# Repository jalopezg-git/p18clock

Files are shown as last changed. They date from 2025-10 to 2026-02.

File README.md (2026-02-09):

# p18clock: a PIC18-based alarm clock

## Introduction
p18clock is an alarm clock based on a PIC18F2550 microcontroller.
The project leverages the [libledmtx](https://github.com/jalopezg-git/libledmtx/) library to drive a LED dot matrix display.

p18clock includes the following features:
- Time and date function
- Display temperature in degrees Celsius
- 24h alarm
- AUTO: display current time, but start a vertical scroll showing additional lines (day-of-the-week, day-of-the-month and month, temperature) every five minutes.

[p18clock-unsharp.mp4](https://github.com/user-attachments/assets/c53c3382-a4fd-4352-af9d-7081afe7f925)

The clock is based on a finite state machine that is described in the following diagram.
It has four push buttons: MODE, SET, UP, DOWN.  MODE triggers the transition between main states.  SET can be used to cycle across sub-states.  UP/DOWN can be used to change the value for a setting.
For more information, see the [p18clock user manual](https://github.com/jalopezg-git/p18clock/blob/master/user-manual/INDEX-EN.md).

```
                                             B_MODE
        ,-----------------------------------------------------------------------------------.
       v                                                                                    `|
 +------------+        +------------+        +------------+        +-------------+        +------------+
 | STATE_TIME | -----> | STATE_DATE | -----> | STATE_TEMP | -----> | STATE_ALARM | -----> | STATE_AUTO |
 +------------+ B_MODE +------------+ B_MODE +------------+ B_MODE +-------------+ B_MODE +------------+
    |       ^             |       ^             |      ^              |        ^
    | B_SET  \            | B_SET  \            | B_SET \             | B_SET  |
    v         `           v         `           v        `            v         `
 +----------+  `       +----------+  `       +---------+  `        +----------+  `
 | _SETHOUR |  |       | _SETMDAY |  |       | _SETVDD |  |        | _SETHOUR |  |
 +----------+  |       +----------+  |       +---------+  |        +----------+  |
    | B_SET    |          | B_SET    |          | B_SET   |           | B_SET    |
    v          |          v          |          v         |           v          |
 +----------+  ,       +----------+  |       +---------+  ,        +----------+  ,
 | _SETMIN  |--        | _SETMON  |  |       | _SETOFF |--         | _SETMIN  |--
 +----------+          +----------+  |       +---------+           +----------+
                          | B_SET    |
                          v          |
                       +----------+  ,
                       | _SETYEAR |--
                       +----------+

STATE_TIME: Display current time		STATE_DATE: Display current date
STATE_TEMP: Display temperature			STATE_ALARM: Display scheduled alarm
STATE_AUTO: Auto-cycle display modes above

_SETHOUR: Set current time - hour		_SETMIN: Set current time - minutes

_SETMDAY: Set current date - day		_SETMON: Set current date - month
_SETYEAR: Set current date - year

_SETVDD: Manually set VDD (if HLVD fails)	_SETOFF: Set temperature offset, e.g. to compensate
	 	      	     	  	  	         for a specific physical location

_ALARM_SETHOUR: Set alarm time - hour		_ALARM_SETMIN: Set alarm time - minutes
```

## Compiling
In addition to [sdcc](https://sdcc.sourceforge.net/), p18clock requires a libledmtx installation in the `$HOME/.local/libledmtx/` directory:
```bash
$ git clone --depth=1 https://github.com/jalopezg-git/libledmtx/
$ cd libledmtx/
$ make
$ make INSTALL_PREFIX=$HOME/.local/libledmtx/ install
$ cd ../
```

Afterwards, p18clock can be built as follows:
```bash
$ # Generate `p18clock.hex`; the image can be flashed into the MCU via pk2cmd
$ make P18CLOCK_LANG=EN # or `P18CLOCK_LANG=ES` to use Spanish translation
```

Additional arguments can be passed to `make` in order to enable/disable specific features; specifically,
- `LARGE_DISPLAY=1`: build for latest p18clock hardware (builtin 40x8 display); if not defined, build targets a 32x7 display.
- `REVERSE_PUSHB_ORDER=1`: define if the PCB has push buttons laid out in reverse order.
- `P18F2550=1`: define to target the PIC18F2550 MCU (still in the original prototype).

## Hardware
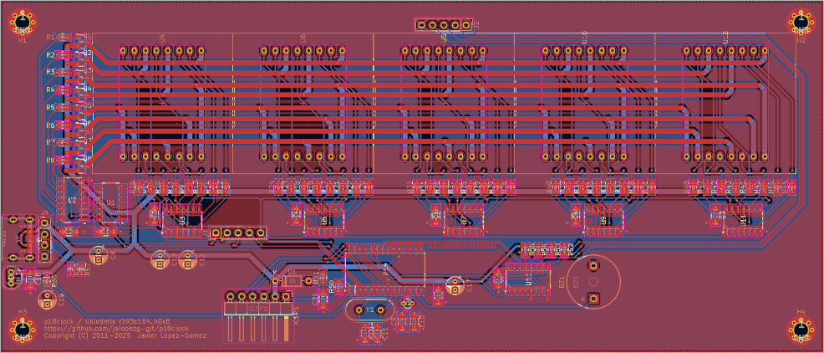
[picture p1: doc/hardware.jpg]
p18clock hardware


For the KiCAD project see [here](https://github.com/jalopezg-git/p18clock/tree/master/hardware/kicad/), which includes both the latest circuit schematic and the PCB layout.
The display is made up of five 8x8 KYX-1088B parts where row pins have been physically connected, thus resulting in a 40x8 LED matrix.
For more details, refer to the libledmtx [hardware description](https://github.com/jalopezg-git/libledmtx/#hardware).

Push buttons are wired to a 74HC148 binary encoder whose output is connected to RB<1:3>; this makes it possible to have up to 7 push buttons using few I/O pins.
A change on a PORTB pin triggers a INT0 interrupt.
The INT0 handler places the corresponding message in a circular buffer, that is to be dispatched from the main loop.

100 nF decoupling capacitors are placed near the Vdd lines of the microcontroller, together with two 4.7 uF "bulk" capacitors placed near the power lines on the board.

The secondary oscillator used as a RTC is a 32.768 kHz crystal.
Temperature measuring is based on the well-known LM35 temperature sensor.

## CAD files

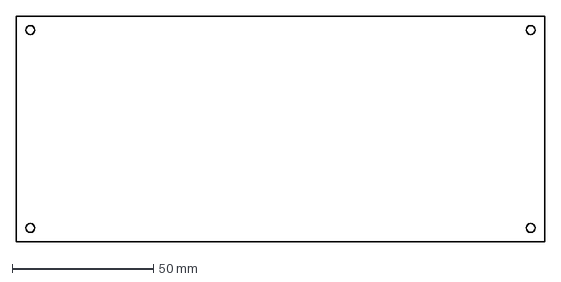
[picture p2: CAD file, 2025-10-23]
hardware/qcad/p18clock_acrylic_cover.dxf
187.2 x 80.0 mm

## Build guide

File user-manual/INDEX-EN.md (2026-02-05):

# p18clock user manual
p18clock exposes four control switches.  Specifically,
- `MODE`: alternates between different display modes.
- `SET`: enter 'assign' mode / accept value.
- `UP`: increment value having input focus / increase brightness.
- `DOWN`: decrement value having input focus / decrease brightness.

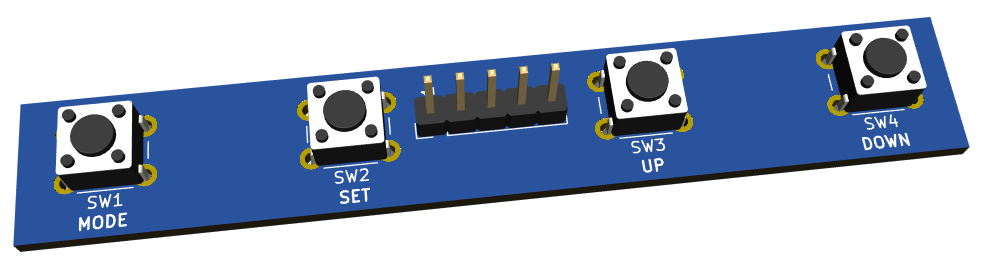
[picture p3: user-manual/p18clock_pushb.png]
p18clock_pushb PCB


> [!TIP]
> Note that buttons may be pressed and held, which after some delay will simulate repeated switch presses.

## p18clock boot
During boot, p18clock will produce a short beep and will display the firmware version and the underlying libledmtx build in use.  It then enters [Time setting mode](#time-setting-mode).

## Display modes
p18clock features five different display modes: TIME, DATE, TEMPERATURE, ALARM, and AUTO.  While being in any of these modes, the `MODE` switch can be used to cycle between the different states.

```mermaid
  graph TD;
      TIME-->DATE;
      DATE-->TEMPERATURE;
      TEMPERATURE-->ALARM;
      ALARM-->AUTO;
      AUTO-->TIME;
```

> [!NOTE]
> `UP` / `DOWN` can be used, respectively, to increase / decrease display brightness :level_slider: in any of the five display modes.  Eight brightness levels are available.
> Input current varies with the brightness level (see [Electrical characteristics](#electrical-characteristics) for details).  The brightness level is not remembered across reboots.

### TIME
No distractions -- this mode continuously displays the current time.  If an alarm is set, a small indicator is shown on the right.
To enter time setting mode, press `SET`.

#### Time setting mode
Use `UP` / `DOWN` to choose a value for the hour; then, press `SET` to move focus to the minutes.  Use `UP` / `DOWN` again to choose a value for the minutes.  Finally, press `SET` to return to the TIME display mode.

### DATE
This mode alternates between different parts of the date (day of the week, day of the month, month, year).  To enter date setting mode, press `SET`.

Staying in this mode for a while may be a bit annoying, and it is expected to be improved in the future.

#### Date setting mode
Use `UP` / `DOWN` to choose the month; press `SET` to confirm the selection.  Use `UP` / `DOWN` to set the current year; then, press `SET`.  Finally, use `UP` / `DOWN` to choose the day of the month.  The day of the week is automatically detected.  Press `SET` again to make the changes effective.

### TEMPERATURE
This mode displays the current room temperature, sampled every 20 seconds.  Temperature range is 0--100 degrees Celsius.

### ALARM
Alarm time is displayed in this mode (or `--:--` if alarm is not set).
To set an alarm :bell:, press the `SET` button; then use `UP` / `DOWN` to choose the hour.  Press `SET` to move input focus to the minutes.  Use `UP` / `DOWN` again to set the minutes, and push `SET` to fix the alarm time.
The 'alarm-enabled' indicator shall be shown in the TIME and AUTO display modes.

#### Acknowledging / Cancelling an alarm
When the alarm is activated, it can be acknowledged by pressing any of the buttons.  Acknowledging the alarm effectively leaves it disabled again (`--:--`).

If an alarm is set, it can be cancelled :no_bell: at any time from the ALARM mode by pushing `SET`, then `MODE`.  The display will show `--:--`.

### AUTO
This mode shows the current time by default and, every five minutes, it starts a vertical scroll to expose additional lines: day of the week, day (of the month) and month, and temperature.
This vertical scroll happens twice and is then rescheduled to happen again after five minutes.  It can also be forced at any time by pressing `SET`.  If `SET` is held, it will temporarily trigger faster scrolling.

## Advanced aspects

### LM35 temperature sensor read calibration
The LM35 sensor output signal usually increases by 10mV per Celsius degree.  This analog signal is then fed to one Analog-to-Digital Converter (ADC) in the MCU.
Because the reference voltage for signal conversion (Vref) matches the input voltage (Vcc), Vcc has to be reliably determined for accurate temperature measurement.  This should happen automatically during boot.

However, in the event that you are experiencing unreliable temperature sampling, a couple of manual adjustments are accessible from the TEMPERATURE display mode by pressing `SET`:
- (V)oltage: this enables override of the auto-detected input voltage.
- (of)fset: a linear offset to apply to the measured temperature before displaying it (defaults to 0).  For instance, a value of -2 will internally subtract two degrees w.r.t. the actual measurement.

### Notifying bugs
If you think that p18clock does not behave as expected or that it has a clear software defect, feel free to create an issue [here](../../../issues/).

### Electrical characteristics
| | Value |
| --- | --- |
| Input voltage | DC 3.1v -- 5v |
| Average input current | ~30mA (lowest brightness) -- ~340mA (highest) |

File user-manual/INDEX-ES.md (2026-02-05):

# Manual de usuario de p18clock
p18clock cuenta con cuatro botones de control.  Específicamente,
- `MODE`: alterna entre diferentes modos de visualización.
- `SET`: entra en modo 'asignación' / acepta un valor.
- `UP`: incrementar valor / incrementa el brillo.
- `DOWN`: decrementar valor / incrementa el brillo.

p18clock_pushb PCB

> [!TIP]
> Nótese que los botones pueden ser presionados y mantenidos, lo que después de un retardo simulará presiones repetidas.

## Arranque de p18clock
Durante el arranque, p18clock producirá un bip corto y mostrará la versión de firmware y la compilación de libledmtx subyacente.  Después, entra en [Modo de fijación de hora](#modo-de-fijacion-de-hora).

## Modos de visualización
p18clock tiene cinco modos de visualización diferentes: HORA, FECHA, TEMPERATURA, ALARMA, y AUTO.  Mientras se está en cualquiera de estos modos, el botón `MODE` puede usarse para cambiar entre los diferentes estados.

```mermaid
  graph TD;
      HORA-->FECHA;
      FECHA-->TEMPERATURA;
      TEMPERATURA-->ALARMA;
      ALARMA-->AUTO;
      AUTO-->HORA;
```

> [!NOTE]
> `UP` / `DOWN` pueden usarse, respectivamente, para incrementar / decrementar el brillo de la pantalla :level_slider: desde cualquiera de los cinco modos de visualización.  Hay disponibles ocho niveles de brillo.
> La corriente de entrada varía con el nivel de brillo (ver [Características eléctricas](#caracteristicas-electricas) para más detalles).  El nivel de brillo no se recuerda entre reinicios.

### HORA
Sin distracciones -- este modo muestra la hora actual continuamente.  Si hay una alarma establecida, un pequeño indicador se muestra en el lado derecho.
Para entrar en el modo de fijación de hora, pulse `SET`.

#### Modo de fijación de hora
Use `UP` / `DOWN` para elegir un valor para la hora; después, presione `SET` para mover el foco a los minutos.  Use `UP` / `DOWN` de nuevo para elegir un valor para los minutos.  Finalmente, presione `SET` para volver al modo de visualización HORA.

### FECHA
Este modo alterna entre diferentes partes de la fecha (día de la semana, día del mes, mes, año).  Para entrar en el modo de fijación de fecha, presione `SET`.

Permanencer en este modo por algún tiempo puede resultar un poco molesto, y se espera que sea mejorado en el futuro.

#### Modo de fijación de fecha
Use `UP` / `DOWN` para elegir el mes; presione `SET` para confirmar la selección.  Use `UP` / `DOWN` para establecer el año actual; después, presione `SET`.  Finalmente, use `UP` / `DOWN` para elegir el día del mes.  El día de la semana se detecta automáticamente.  Presione `SET` de nuevo para hacer que los cambios sean efectivos.

### TEMPERATURA
Este modo muestra la temperatura de la habitación, muestreada cada 20 segundos.  El intervalo de temperatura es de 0--100 grados Celsius.

### ALARMA
En este modo se muestra la hora de alarma (o `--:--` si no hay una alarma establecida).
Para establecer una alarma :bell:, presione el botón `SET`; después use `UP` / `DOWN` para elegir la hora.  Presione `SET` para mover el foco de entrada a los minutos.  Use `UP` / `DOWN` de nuevo para establecer los minutos y pulse `SET` para fijar la hora de alarma.
El indicador de 'alarma-habilitada' será mostrado en los modos de visualización HORA y AUTO.

#### Reconociendo / Cancelando una alarma
Cuando la alarma se activa, puede reconocerse presionando cualquiera de los botones.  Reconocer la alarma la deja efectivamente deshabilitada (`--:--`).

Si hay una alarma establecida, puede cancelarse :no_bell: en cualquier momento desde el modo ALARMA pulsando `SET` y después `MODE`.  La pantalla mostrará `--:--`.

### AUTO
De forma predeterminada, este modo muestra la hora actual y, cada cinco minutos, comienza un desplazamiento vertical que expone líneas adicionales: día de la semana, día (del mes) y mes, y temperatura.
Este desplazamiento vertical ocurre dos veces y es replanificado para ocurrir de nuevo cinco minutos después.  También puede forzarse en cualquier momento pulsando `SET`.  Si `SET` se mantiene, activará temporalmente un desplazamiento más rápido.

## Aspectos avanzados

### Calibración de lecturas del sensor de temperatura LM35
La señal de salida del sensor LM35 normalmente se incrementa a razón de 10mV por grado Celsius.  Esta señal analógica se alimenta entonces a un Conversor Analógico-a-Digital (ADC) en el microcontrolador.
Debido a que el voltage de referencia para la conversión de la señal (Vref) coincide con el voltage de entrada (Vcc), Vcc tiene que determinarse de forma fiable para una medición de temperatura precisa.  Esto debería ocurrir automáticamente durante el arranque.

Sin embargo, en el caso de que esté experimentando muestreos de temperatura imprecisos, un par de ajustes manuales están accesibles desde el modo de visualización TEMPERATURA presionando `SET`:
- (V)oltage: permite especificar un voltage de entrada diferente del auto-detectado.
- (of)fset: un desplazamiento lineal que se aplica a la temperatura medida antes de ser mostrada (por defecto 0).  Por ejemplo, un valor de -2 restará internamente dos grados con respecto de la medición real.

### Notificando bugs
Si cree que p18clock no se comporta como espera o que tiene un claro defecto de software, cree una issue [aquí](../../../issues/).

### Características eléctricas
| | Valor |
| --- | --- |
| Voltage de entrada | DC 3.1v -- 5v |
| Corriente de entrada (avg.) | ~30mA (brillo más bajo) -- ~340mA (más alto) |

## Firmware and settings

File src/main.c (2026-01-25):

/*
 * main.c - p18clock source file
 *
 * Copyright (C) 2011-2026  Javier Lopez-Gomez
 *
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
 * You should have received a copy of the GNU General Public License
 * along with this program; if not, write to the Free Software
 * Foundation, Inc., 59 Temple Place - Suite 330, Boston, MA 02111-1307, USA
 */

// clang-format off
#include <ledmtx_scrollstr.h>

#include <ledmtx_config.h>
#include <ledmtx_core.h>
#include <ledmtx_fontstd.h>
#include <ledmtx_stdio.h>
#if LEDMTX_HAVE_VIEWPORT != 1
#error p18clock requires a libledmtx build that has ENABLE_VIEWPORT=1

#endif

#include <delay.h>
#include <signal.h>
#include <stdio.h>
// clang-format on

#include <lang.h>
#include <lm35.h>
#include <rbuf.h>

#include "ledmtx_modegen_modes.h"
extern unsigned int __ledmtx_r393c164_E_softpwm_tmr3;
extern void __ledmtx_r393c164_E_softpwm_duty_end;

/* CONFIG1L */
#if defined(__SDCC_PIC18F2550)
#pragma config USBDIV = 1 // USB clock source comes directly from the primary
                          // oscillator block with no postscale
#pragma config CPUDIV =                                                        \
    OSC1_PLL2             // [Primary Oscillator Src: /1][96 MHz PLL Src: /2]
#pragma config PLLDIV = 2 // Divide by 2 (8 MHz oscillator input)
#endif                    /* __SDCC_PIC18F2550 */

/* CONFIG1H */
#if defined(__SDCC_PIC18F2550)
#pragma config FOSC = HS // HS oscillator (HS)
#else
#pragma config OSC = HS // HS oscillator (HS)
#endif                  /* __SDCC_PIC18F2550 */

/* CONFIG2L */
#if defined(__SDCC_PIC18F2550)
#pragma config BOR = OFF // Brown-out Reset disabled in hardware and software
#else
#pragma config BOREN = OFF // Brown-out Reset disabled in hardware and software
#endif                     /* __SDCC_PIC18F2550 */
#pragma config BORV = 2    // Setting 1 2.79V

/* CONFIG2H */
#pragma config WDT = OFF // WDT disabled

/* CONFIG3H */
#if defined(__SDCC_PIC18F2550)
#pragma config CCP2MX = ON // CCP2 input/output is multiplexed with RC1
#else
#pragma config CCP2MX = PORTC // CCP2 input/output is multiplexed with RC1
#endif                        /* __SDCC_PIC18F2550 */

#pragma config PBADEN =                                                        \
    OFF // PORTB<4:0> pins are configured as digital I/O on Reset
#pragma config LPT1OSC = OFF // Timer1 configured for higher power operation
#pragma config MCLRE = ON    // MCLR pin enabled; RE3 input pin disabled

/* CONFIG4L */
#pragma config STVREN = ON // Stack full/underflow will cause Reset
#pragma config LVP = OFF   // Single-Supply ICSP disabled
#pragma config XINST =                                                         \
    OFF // Instruction set extension and Indexed Addressing mode disabled
        // (Legacy mode); XINST not supported in SDCC
#pragma config DEBUG = OFF // Background debugger disabled, RB6 and RB7
                           // configured as general purpose I/O

/* The IDLOC0, IDLOC1, and IDLOC2 bytes store the firmware version */
__CONFIG(__IDLOC0, 2);
__CONFIG(__IDLOC1, 1);
__CONFIG(__IDLOC2, 0);

#define ARRAY_SIZE(x) (sizeof(x) / sizeof(x[0]))
#define UNDEF ((unsigned char)-1)

/// Interval (in seconds) that separates two LM35 samples.
#define TEMPERATURE_INTERVAL 20

// Interval (in minutes) before entering vertical scroll in AUTO mode.
#define AUTO_INTERVAL 5

/* PWM 2.44khz@50 (Fosc=8mhz).  See Sec. 14.4 'CAPTURE/COMPARE/PWM (CCP)
 * MODULES', PWM Mode in the PIC18F2X1X/4X1X datasheet for further information.
 */
#define CCP1_PR2 0xcb
#define CCP1_R 0x066
#define T2CON_PRESCALE 0x01

/// Base configuration for re-queueing last keystroke.  Timer2 postscale only
/// impacts interrupt-on-overflow and is not used in determination of PWM
/// frequency (see note in datasheet, Sec. 14.4).
/// The frequency after the postscale is ~152.5 Hz, i.e. the first repetition
/// will happen after ~1s; the rest after ~0.1s.
#define T2CON_POSTSCALE 0x0f
#define INPUT_REP_DELAY_INITIAL 152
#define INPUT_REP_DELAY 15

LEDMTX_BEGIN_MODULES_INIT
LEDMTX_MODULE_INIT(scrollstr)
LEDMTX_END_MODULES_INIT

LEDMTX_DECLARE_FRAMEBUFFER(LEDMTX__DEFAULT_WIDTH, LEDMTX__DEFAULT_HEIGHT)

#if defined(__P18CLOCK_LARGE_DISPLAY)
#define LEDMTX_VIEWPORT_HEIGHT 8
#define P18CLOCK_FONT_SMALL ledmtx_font5x7
#define P18CLOCK_FONT_LARGE ledmtx_font6x8

#else
#define LEDMTX_VIEWPORT_HEIGHT 7
#define P18CLOCK_FONT_SMALL ledmtx_font5x7
#define P18CLOCK_FONT_LARGE ledmtx_font5x7

#endif /* __P18CLOCK_LARGE_DISPLAY */

#define CLASS_INPUT (0 << 6)
#define CLASS_RTC (1 << 6)

/// A circular buffer is used to communicate ISR code with the main loop.  Data
/// is typically queued from an ISR and dispatched from the main loop. The 2 MSb
/// of a message are reserved for the message class, i.e., a tag that groups
/// messages according to their semantics.
#define MESSAGE_CLASS(m) (m & 0xc0)

/// The year has changed and `_days_per_month[1]` may need updating per
/// definition of leap year
#define YEARCHG (CLASS_RTC | 0x00)

/// The corresponding button has been pushed
#if !defined(__P18CLOCK_REVERSE_PUSHB_ORDER)
#define B_MODE (CLASS_INPUT | 0x08)
#define B_SET (CLASS_INPUT | 0x0a)
#define B_UP (CLASS_INPUT | 0x0c)
#define B_DOWN (CLASS_INPUT | 0x0e)

#else
#define B_MODE (CLASS_INPUT | 0x0e)
#define B_SET (CLASS_INPUT | 0x0c)
#define B_UP (CLASS_INPUT | 0x0a)
#define B_DOWN (CLASS_INPUT | 0x08)

#endif /* __P18CLOCK_REVERSE_PUSHB_ORDER */

DECLARE_RBUF(_mbuf, 32)

// # Summary of PIC peripheral usage:
// - Timer0: used by libledmtx ISR and INT0 interrupt unmasking
// - Timer1: used by RTC; external 32.768 kHz clock
// - Timer2/CCP1: used by CCP1 module in PWM mode (buzzer) / keystroke re-queue
// - Timer3: `r393c164` experimental software-based PWM (brightness adjustment)
//
// # External interrupt sources:
// - INT0: user input (keystroke)
DEF_INTHIGH(_high_int)
DEF_HANDLER(SIG_TMR1, _tmr1_handler)
DEF_HANDLER(SIG_INT0, _int0_handler)
DEF_HANDLER(SIG_TMR2, _tmr2_handler)
END_DEF

DEF_INTLOW(_low_int)
DEF_HANDLER(SIG_TMR0, _tmr0_handler)
DEF_HANDLER(SIG_TMR3, __ledmtx_r393c164_E_softpwm_duty_end)
END_DEF

/// Number of days for each month of the year in the Gregorian calendar
static unsigned char _days_per_month[] = {31, 28, 31, 30, 31, 30,
                                          31, 31, 30, 31, 30, 31};

#define LEAP_YEAR(year)                                                        \
  ((((year % 4) == 0) && ((year % 100) != 0)) || ((year % 400) == 0))

#define YEAR_MIN 2000
#define YEAR_MAX 2099

/// Struct that holds the current date and time
volatile struct {
  unsigned char sec;
  unsigned char min;
  unsigned char hour;
  unsigned char mday;
  unsigned char mon;
  unsigned int year;
} _time = {0, 0, 0, 1, 1, YEAR_MIN};

/// Struct that holds information about the alarm
static struct {
  unsigned char hour;
  unsigned char min;
  unsigned ena : 1;
  unsigned nack : 1;
  unsigned : 6;
} _alarm = {0, 0, 0, 0};

/// Last LM35 measurement, in Celsius degrees.
static int _temperature = 0;

// clang-format off
SIGHANDLERNAKED(_tmr1_handler)
{
  __asm
  extern _rbuf_put
  bsf		_TMR1H, 7, 0
  bcf		_PIR1, 0, 0		; TMR1IF ack interrupt
  
  banksel	__time+0
  incf		__time+0, f		; _time.sec++
  movlw		59
  cpfsgt	__time+0
  retfie	1
  
  ; _time.sec overflow
  clrf		__time+0		; _time.sec=0
  banksel	__time+1
  incf		__time+1, f		; _time.min++
  ;movlw	59
  cpfsgt	__time+1
  retfie	1
  
  ; _time.min overflow
  clrf		__time+1		; _time.min=0
  banksel	__time+2
  incf		__time+2, f		; _time.hour++
  movlw		23
  cpfsgt	__time+2
  retfie	1
  
  ; _time.hour overflow
  clrf		__time+2		; _time.hour=0
  movff		_FSR0H, _POSTDEC1	; push FSR0x
  movff		_FSR0L, _POSTDEC1
  lfsr		0, __days_per_month
  banksel	__time+4
  decf		__time+4, w
  movf		_PLUSW0, w, 0		; _days_per_month[_time.mon-1] -> WREG
  banksel	__time+3
  incf		__time+3, f		; _time.mday++
  cpfsgt	__time+3
  bra		@tmr1__ret
  
  ; _time.mday overflow
  movlw		1
  movwf		__time+3		; _time.mday=1
  banksel	__time+4
  incf		__time+4, f		; _time.mon++
  movlw		12
  cpfsgt	__time+4
  bra		@tmr1__ret
  
  ; _time.mon overflow
  movlw		1
  movwf		__time+4		; _time.mon=1
  banksel	__time+5
  incf		__time+5, f		; _time.year++
  btfsc		_STATUS, 0, 0		; C
  incf		__time+6, f
  
  movlw		high __mbuf		; push &_mbuf
  movwf		_POSTDEC1, 0
  movlw		low __mbuf
  movwf		_POSTDEC1, 0
  movlw		YEARCHG			; put YEARCHG
  call		_rbuf_put
  movlw		2
  addwf		_FSR1L, f, 0
  
@tmr1__ret:
  movff		_PREINC1, _FSR0L	; pop FSR0x
  movff		_PREINC1, _FSR0H
  retfie	1
  __endasm;
}
// clang-format on

#define INT0_UNMASK_TIMEOUT 14
/// INT0 interrupt is externally triggered on RB0/INT0 pin.  RB0:RB3 is
/// (indirectly) driven by push buttons, and thus requires some debouncing
/// logic. In particular, `_int0_handler` masks INT0 interrupts for some
/// time after which they are enabled again.  This interval is given by
/// `INT0_UNMASK_TIMEOUT`.
static volatile unsigned char _int0_timeout;
static volatile unsigned char _input_rep_timeout;

/// Queue user input (4 LSb of PORTB) in the `_mbuf` message buffer.
// clang-format off
void I_queue_keystroke(void) __naked
{
  __asm
  movlw		high __mbuf		; push &_mbuf
  movwf		_POSTDEC1, 0
  movlw		low __mbuf
  movwf		_POSTDEC1, 0
  movlw		0x0f			; put (PORTB&0x0f)|CLASS_INPUT
  andwf		_PORTB, w, 0
  iorlw		CLASS_INPUT
  call		_rbuf_put
  movlw		2
  addwf		_FSR1L, f, 0
  return
  __endasm;
}
// clang-format on

// clang-format off
SIGHANDLERNAKED(_int0_handler)
{
  __asm
  bcf		_INTCON, 1, 0		; ack interrupt
  btfsc		_INTCON2, 6, 0
  bra		@int0__rising_edge

  ;; Triggered due to falling edge, i.e. key press
  movff		_FSR0H, _POSTDEC1	; push FSR0x
  movff		_FSR0L, _POSTDEC1
  call		_I_queue_keystroke
  movff		_PREINC1, _FSR0L	; pop FSR0x
  movff		_PREINC1, _FSR0H

  movlw		INPUT_REP_DELAY_INITIAL
  banksel	__input_rep_timeout
  movwf		__input_rep_timeout
  bsf		_T2CON, 2, 0
@int0__toggle_edge:
  bcf		_INTCON, 4, 0		; mask INT0 interrupt
  btg		_INTCON2, 6, 0		; toggle edge
  movlw		INT0_UNMASK_TIMEOUT	; INT0 unmasking is done in _tmr0_handler
  banksel	__int0_timeout
  movwf		__int0_timeout
  retfie	1

  ;; Triggered due to rising edge, i.e. key release
@int0__rising_edge:
  bcf		_T2CON, 2, 0
  bra		@int0__toggle_edge
  __endasm;
}
// clang-format on

// clang-format off
SIGHANDLERNAKED(_tmr2_handler)
{
  __asm
  bcf		_PIR1, 1, 0		; TMR2IF ack interrupt
  btfsc		_PORTB, 0, 0		; INT0 pin driven high, i.e. key released; stop Timer2
  bra		@tmr2__stop
  banksel	__input_rep_timeout
  decfsz	__input_rep_timeout, f	; return if `--_input_rep_timeout != 0`
  retfie	1

  movff		_FSR0H, _POSTDEC1	; push FSR0x
  movff		_FSR0L, _POSTDEC1
  call		_I_queue_keystroke
  movff		_PREINC1, _FSR0L	; pop FSR0x
  movff		_PREINC1, _FSR0H

  movlw		INPUT_REP_DELAY
  banksel	__input_rep_timeout
  movwf		__input_rep_timeout
  retfie	1

@tmr2__stop:
  bcf		_INTCON2, 6, 0		; restore INTEDG0 (falling edge)
  bcf		_T2CON, 2, 0
  retfie	1
  __endasm;
}
// clang-format on

// clang-format off
SIGHANDLERNAKED(_tmr0_handler)
{
  LEDMTX_BEGIN_ISR
  LEDMTX_BEGIN_R0
  ledmtx_scrollstr_interrupt();
  LEDMTX_END_R0
  
  LEDMTX_VERTREFRESH
  
  __asm
  btfsc		_INTCON, 4, 0		; INT0 interrupt masked?
  bra		@int0__unmasked
  
  movff		_BSR, _POSTDEC1		; push BSR
  banksel	__int0_timeout
  dcfsnz	__int0_timeout, f	; _int0_timeout--
  bsf		_INTCON, 4, 0		; _int0_timeout==0? unmask INT0 interrupt
  movff		_PREINC1, _BSR		; pop BSR
@int0__unmasked:
  __endasm;
  
  LEDMTX_END_ISR
}
// clang-format on

/// Carry out initialization tasks, e.g. set the `TRISx` registers and configure
/// peripherals
void uc_init(void) {
  OSCCONbits.IDLEN = 1; // Device enters idle mode on `sleep` instruction

  TRISA = 0xc1;
  PORTA = 0x00;
  TRISB = 0x0f;
  PORTB = 0x00;
  TRISC = 0xfb;
  PORTC = 0x00;
  INTCON2bits.RBPU = 1; // Disable RBx pullup

  lm35_init();

  /* Timer1, see p18f2550 datasheet.  RTC */
  TMR1H = 0x80;
  TMR1L = 0x00;
  T1CON = 0x0f;
  PIE1bits.TMR1IE = 1;
  IPR1bits.TMR1IP = 1;

  /* Timer2 / CCP1 */
  PR2 = CCP1_PR2;
  CCPR1L = (CCP1_R >> 2);
  CCP1CON = (CCP1_R & 0x03) << 4;
  T2CON = (T2CON_POSTSCALE << 3) | (T2CON_PRESCALE & 0x03);
  PIE1bits.TMR2IE = 1;
  IPR1bits.TMR2IP = 1;

  /* Timer3 */
  PIE2bits.TMR3IE = 1;
  IPR2bits.TMR3IP = 0;
  T3CON = 0xa4;
#if (~LEDMTX__DEFAULT_T0CON & 0x08)
#if (LEDMTX__DEFAULT_T0CON & 0x07) > 0x02
#error Timer3: could not match Timer0 prescaler

#endif /* (LEDMTX__DEFAULT_T0CON & 0x07) > 0x02 */
  T3CON |= (1 + (LEDMTX__DEFAULT_T0CON & 0x07)) << 3;

#endif /* (~LEDMTX__DEFAULT_T0CON & 0x08) */
  __ledmtx_r393c164_E_softpwm_tmr3 =
      (LEDMTX__DEFAULT_TMR0H << 8) | LEDMTX__DEFAULT_TMR0L;

  ledmtx_init(LEDMTX_INIT_CLEAR | LEDMTX_INIT_TMR0, LEDMTX__DEFAULT_WIDTH,
              LEDMTX__DEFAULT_HEIGHT, LEDMTX__DEFAULT_TMR0H,
              LEDMTX__DEFAULT_TMR0L, LEDMTX__DEFAULT_T0CON);
  // Framebuffer is either 32x31 or 40x35; set initial viewport height. Vertical
  // scroll is simulated in p18clock by changing the viewport.
  ledmtx_setviewport(0, 0, LEDMTX__DEFAULT_WIDTH, LEDMTX_VIEWPORT_HEIGHT);

  INTCON2bits.INTEDG0 = 0; // INT0 triggered on falling edge
  INTCONbits.INT0IE = 1;

  _temperature = lm35_get();
}

/// Return the day of the week for the given date, i.e. 0 - Sunday, 1 - Monday,
/// ..., 6 - Saturday. Implements the Tomohiko Sakamoto's day-of-the-week
/// algorithm.
char day_of_week(unsigned char mday, unsigned char mon, unsigned int year) {
  static const char t[] = {0, 3, 2, 5, 0, 3, 5, 1, 4, 6, 2, 4};
  year -= mon < 3;
  return (year + (year / 4) - (year / 100) + (year / 400) + t[mon - 1] + mday) %
         7;
}

// clang-format off
/// Enumeration of the possible states of the FSM below.  Transition between
/// main states is triggered by B_MODE; B_SET transitions between sub-states,
/// if applicable.
///                                             B_MODE
///        ,-----------------------------------------------------------------------------------.
///       v                                                                                    `|
/// +------------+        +------------+        +------------+        +-------------+        +------------+
/// | STATE_TIME | -----> | STATE_DATE | -----> | STATE_TEMP | -----> | STATE_ALARM | -----> | STATE_AUTO |
/// +------------+ B_MODE +------------+ B_MODE +------------+ B_MODE +-------------+ B_MODE +------------+
///    |       ^             |       ^             |      ^              |        ^
///    | B_SET  \            | B_SET  \            | B_SET \             | B_SET  |
///    v         `           v         `           v        `            v         `
/// +----------+  `       +----------+  `       +---------+  `        +----------+  `
/// | _SETHOUR |  |       | _SETMDAY |  |       | _SETVDD |  |        | _SETHOUR |  |
/// +----------+  |       +----------+  |       +---------+  |        +----------+  |
///    | B_SET    |          | B_SET    |          | B_SET   |           | B_SET    |
///    v          |          v          |          v         |           v          |
/// +----------+  ,       +----------+  |       +---------+  ,        +----------+  ,
/// | _SETMIN  |--        | _SETMON  |  |       | _SETOFF |--         | _SETMIN  |--
/// +----------+          +----------+  |       +---------+           +----------+
///                          | B_SET    |
///                          v          |
///                       +----------+  ,
///                       | _SETYEAR |--
///                       +----------+
// clang-format on
#define STATE_TIME 0x00
#define STATE_DATE 0x01
#define STATE_TEMP 0x02
#define STATE_ALARM 0x03
#define STATE_AUTO 0x04
#define STATE_TIME_SETHOUR 0x05
#define STATE_TIME_SETMIN 0x06
#define STATE_DATE_SETMDAY 0x07
#define STATE_DATE_SETMON 0x08
#define STATE_DATE_SETYEAR 0x09
#define STATE_TEMP_SETVDD 0x0a
#define STATE_TEMP_SETOFF 0x0b
#define STATE_ALARM_SETHOUR 0x0c
#define STATE_ALARM_SETMIN 0x0d

#define is_main_state(x)                                                       \
  (x == STATE_TIME || x == STATE_DATE || x == STATE_TEMP ||                    \
   x == STATE_ALARM || x == STATE_AUTO)

/// The current state of the FSM
static unsigned char _state = STATE_TIME_SETHOUR;

/// A single descriptor (and NUL-terminated string) is used for scrolling text.
static char _tmpstr[64];
static struct ledmtx_scrollstr_desc _scroll_desc = {2,
                                                    2,
                                                    ledmtx_scrollstr_step,
                                                    LEDMTX_VIEWPORT_HEIGHT,
                                                    LEDMTX__DEFAULT_WIDTH,
                                                    0,
                                                    0,
                                                    (__data char *)_tmpstr,
                                                    0,
                                                    1,
                                                    0x80,
                                                    ledmtx_scrollstr_stop,
                                                    0x00};

/// Schedule a text for asynchronous scroll (see Timer0 handler), and wait for
/// its finalization.
/// Temporarily use a smaller font s.t. more characters fit the display.
#define SYNC_SCROLL(d)                                                         \
  do {                                                                         \
    ledmtx_setfont(P18CLOCK_FONT_SMALL);                                       \
    ledmtx_scrollstr_start(&d);                                                \
    while (d.str[d.i] != 0 || d.charoff != 0)                                  \
      IDLE();                                                                  \
    ledmtx_scrollstr_reset(&d);                                                \
    ledmtx_setfont(P18CLOCK_FONT_LARGE);                                       \
  } while (0)

#define ENABLE_BUZZER()                                                        \
  do {                                                                         \
    PIE1bits.TMR2IE = 0;                                                       \
    T2CONbits.TMR2ON = 1;                                                      \
    CCP1CON |= 0x0c;                                                           \
  } while (0)

#define DISABLE_BUZZER()                                                       \
  do {                                                                         \
    CCP1CON &= 0xf0;                                                           \
    T2CONbits.TMR2ON = 0;                                                      \
    PIE1bits.TMR2IE = 1;                                                       \
  } while (0)

#define BEEP()                                                                 \
  do {                                                                         \
    ENABLE_BUZZER();                                                           \
    delay10ktcy(1);                                                            \
    DISABLE_BUZZER();                                                          \
  } while (0)

void alarm(void) {
  static unsigned char pstate = 0;

  if ((pstate & 0x04) == 0) {
    if (pstate & 0x01) {
      DISABLE_BUZZER();
    } else {
      ENABLE_BUZZER();
    }
  }
  pstate++;
  pstate &= 0x07;
}

/* `idle_alarm()` counter overflows in ~0.125s */
#define IDLE_ALARM__COUNTER_PRELOAD 0xa9
void idle_alarm(void) {
  static unsigned char counter = IDLE_ALARM__COUNTER_PRELOAD;

  if (_alarm.ena && _alarm.hour == _time.hour && _alarm.min == _time.min) {
    _alarm.ena = 0;
    _alarm.nack = 1;
  }
  if (_alarm.nack && (++counter == 0)) {
    counter = IDLE_ALARM__COUNTER_PRELOAD;
    alarm();
  }
}

#define ACK_ALARM()                                                            \
  do {                                                                         \
    DISABLE_BUZZER();                                                          \
    _alarm.nack = 0;                                                           \
  } while (0)
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
void main(void) {
  static signed char c;
  static unsigned char tmr1h_prev_value = UNDEF;
#define __update_period_elapsed()                                              \
  ((TMR1H ^ tmr1h_prev_value) & 0x20) /* every 0.25s */
#define __force_update() tmr1h_prev_value = TMR1H ^ 0x20
  static unsigned char temp_measurement_sched_sec = UNDEF;

  /* initialisation */
  uc_init();
  ledmtx_setfont(P18CLOCK_FONT_LARGE);
  stdout = STREAM_USER;
  BEEP();

  sprintf(_tmpstr, STR_FMT_INIT, *((__code unsigned char *)__IDLOC0),
          *((__code unsigned char *)__IDLOC1),
          *((__code unsigned char *)__IDLOC2), LEDMTX_GITBRANCH);
  SYNC_SCROLL(_scroll_desc);

  temp_measurement_sched_sec = (_time.sec + TEMPERATURE_INTERVAL) % 60;
  /* main loop */
  while (1) {
    if (_time.sec == temp_measurement_sched_sec) {
      _temperature = lm35_get();
      temp_measurement_sched_sec = (_time.sec + TEMPERATURE_INTERVAL) % 60;
    }

    if (__update_period_elapsed()) {
      _state_fn[_state](NULL);
      tmr1h_prev_value = TMR1H;
    }
    c = rbuf_get(_mbuf);
    if (c != -1) {
      switch (c) {
      case YEARCHG:
        _days_per_month[1] = (LEAP_YEAR(_time.year) ? 29 : 28);
#ifdef STR_FMT_YEARCHG
        sprintf(_tmpstr, STR_FMT_YEARCHG, _time.year);
        SYNC_SCROLL(_scroll_desc);
#endif
        break;

      case B_MODE:
      case B_SET:
      case B_UP:
      case B_DOWN:
        if (_alarm.nack) {
          ACK_ALARM();
        } else {
          if (is_main_state(_state) && (c == B_UP || c == B_DOWN))
            __S_set_dpy_brightness(&c);
          else
            _state_fn[_state](&c);
          __force_update();
        }
        break;
      }
    }

    IDLE();
  }
}

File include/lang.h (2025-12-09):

/*
 * lang.h - language-dependent string literals
 *
 * Copyright (C) 2011-2024  Javier Lopez-Gomez
 *
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
 * You should have received a copy of the GNU General Public License
 * along with this program; if not, write to the Free Software
 * Foundation, Inc., 59 Temple Place - Suite 330, Boston, MA 02111-1307, USA
 */

#ifndef __LANG_H__
#define __LANG_H__

/* English (EN) */
#if defined(LANG_EN)
static __code const char *__code _str_month[] = {"Jan", "Feb", "Mar", "Apr",
                                                 "May", "Jun", "Jul", "Aug",
                                                 "Sep", "Oct", "Nov", "Dec"};

static __code const char *__code _str_day[] = {"Sun", "Mon", "Tue", "Wed",
                                               "Thu", "Fri", "Sat"};

static __code const char *__code _str_state[] = {"TIME", "DATE", "TEMPERATURE",
                                                 "ALARM", "AUTO"};

#define STR_FMT_TEMP " %02u'C"
#define STR_FMT_MDAY "day"
#define STR_FMT_MONTH "m "
#define STR_FMT_YEAR "y"
#define STR_FMT_VDD "V "
#define STR_FMT_OFF "of"
#define STR_FMT_YEARCHG "/\\/ \\/ \\ HAPPY %u! / \\/ \\/\\"

/* Spanish (ES) */
#elif defined(LANG_ES)
static __code const char *__code _str_month[] = {"Ene", "Feb", "Mar", "Abr",
                                                 "May", "Jun", "Jul", "Ago",
                                                 "Sep", "Oct", "Nov", "Dic"};

static __code const char *__code _str_day[] = {"Dom", "Lun", "Mar", "Mie",
                                               "Jue", "Vie", "Sab"};

static __code const char *__code _str_state[] = {"HORA", "FECHA", "TEMPERATURA",
                                                 "ALARMA", "AUTO"};

#define STR_FMT_TEMP " %02u'C"
#define STR_FMT_MDAY "dia"
#define STR_FMT_MONTH "m "
#define STR_FMT_YEAR "a"
#define STR_FMT_VDD "V "
#define STR_FMT_OFF "of"
#define STR_FMT_YEARCHG "/\\/ \\/ \\ FELIZ %u! / \\/ \\/\\"

#else
#error Unsupported language

#endif

#define STR_FMT_INIT "p18clock-%hu.%hu.%hu (libledmtx %s)"
#define STR_FMT_AUTO "%02hu:%02hu\n %s\n%2hu%s\n" STR_FMT_TEMP

#endif // __LANG_H__

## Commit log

2024-12-29 Take a sample from LM35 only every few seconds
2024-12-30 Fix misbehavior near wrap-around for scheduled actions
    [main.c]
2025-01-11 Set temperature measurement interval to 20s
    LM35 measurements may still exhibit some small noise; separate
    samples a bit more.
    [main.c]
2025-10-14 Add p18clock KiCad schematic and PCB layout
    Add p18clock schematic and PCB layout based on libledmtx's
    r393c164_32x8; display has been extended to 40x8.
    [p18clock.kicad_pcb, p18clock.kicad_sch, p18clock_pushb.kicad_pcb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]
2025-10-16 p18clock/r393c164_40x8: fix defects in KiCad schematic / PCB
    [p18clock.kicad_pcb, r393c164_40x8.kicad_sch]
2025-10-23 [kicad] fix defects in KiCad schematic / PCB
    Fix the following defects in KiCad schematic / PCB layout:
    - Added 5k1 pull-down resistors in CC1 / CC2 USB-C pins
    - Routed LM35.OUT signal on F.Cu layer s.t. it does not split B.Cu
    (GND) fill area
    - Added F.Cu (GND) fill area
    [p18clock.kicad_pcb, p18clock.kicad_sch]
2025-10-23 [qcad] Add `p18clock_acrylic_cover.dxf`
    [p18clock_acrylic_cover.dxf]
2025-11-22 Changes required to accommodate hardware updates
    Latest p18clock hardware is based on a PIC18F2510 and a r393c164-based
    40x8 display. Specifically, act on the following `make` variables:
    * `P18F2550`: if defined, build for the PIC18F2550.
    * `LARGE_DISPLAY`: define to build for a 40x8 display; if undefined,
    build for legacy 32x7 display.
    * `REVERSE_PUSHB_ORDER`: define if the PCB has push buttons laid out
    in reverse order.
    [main.c]
2025-11-22 Use a 100Hz refresh rate, both for updated / legacy hardware
2025-12-08 Scroll short `Happy 20xx!` message on year change
    [lang.h, main.c]
2025-12-08 Emit short beep after initialization (useful for debugging)
    [main.c]
2025-12-08 Fix alarm activation issue in latest build
    Alarm was not activated even if `_alarm.ena == 1` due to
    what seems to be a SDCC bug. As a workaround, reorder bit-fields
    in `_alarm`.
    [main.c]
2025-12-11 Fix `main.c:934: warning 94: comparison is always true due to limited range of data type`
    [main.c]
2025-12-15 Fix (lack of) alarm indicator redraw
    `alarm_was_enabled` has to be reset when leaving `S_time()` s.t.
    indicator gets redrawn again if needed.
    [main.c]
2025-12-18 Move alarm-enabled indicator logic to `__S_time_draw_alarm_indicator()`
    As a side effect, this fixes redraw when transitioning from static
    (time only) `S_auto` to `S_time`.
    [main.c]
2026-01-09 Fix debounce delay (missed in 38d34c70d9d7fc6cc6bbb16ad4376f58a92ef3b5)
    [main.c]
2026-01-25 Move keystroke re-queueing from Timer3 to Timer2
2026-01-25 Restore `INTEDG0` to falling edge at end of keystroke repetition
    Fix input issue where `INTEDG0` was sometimes left to 1 (Interrupt
    on rising edge). Make sure it is always restored to `0` in Timer2 ISR.
    [main.c]
2026-02-05 [hardware] Fix errata in XTAL capacitor values
    Swap XTAL capacitors (8MHz should be 12-15pF; 32.768kHz should be
    20-22pF).
    Closes #23.
    [p18clock.kicad_pcb, p18clock.kicad_sch]

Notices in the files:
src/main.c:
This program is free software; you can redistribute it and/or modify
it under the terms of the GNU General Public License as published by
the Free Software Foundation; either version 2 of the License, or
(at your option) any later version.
